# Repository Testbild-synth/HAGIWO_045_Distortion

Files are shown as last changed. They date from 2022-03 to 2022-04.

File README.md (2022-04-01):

# HAGIWO Diode Distortion Eurorack Module
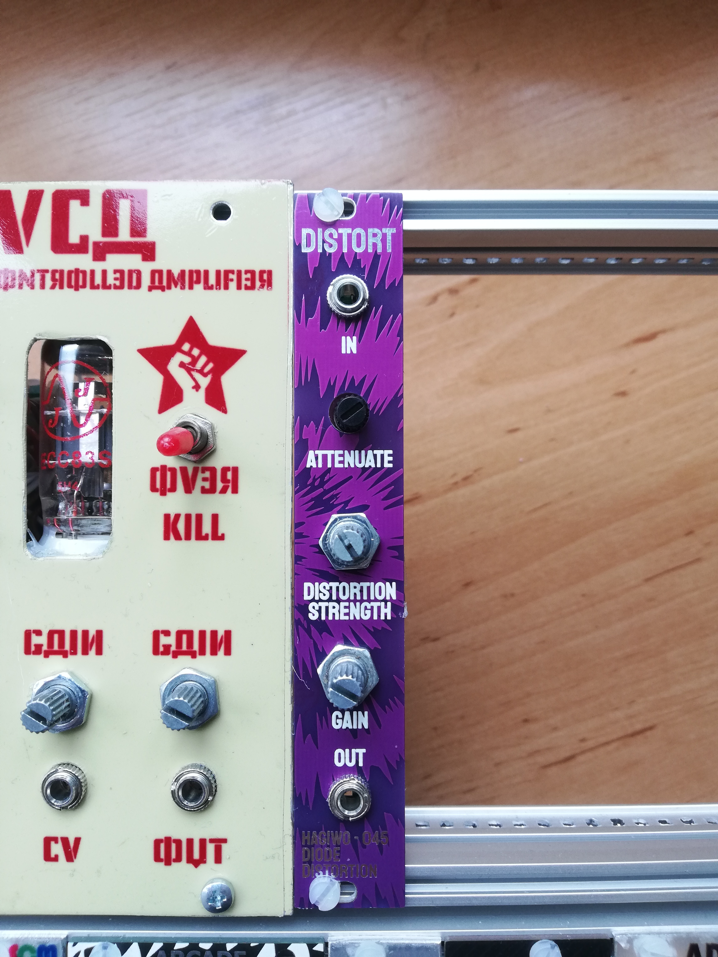
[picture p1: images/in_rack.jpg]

Through-hole 4HP  PCB version of the HAGIWO distortion eurorack module. 

### Current Status: Confirmed working.

## Hardware and PCB

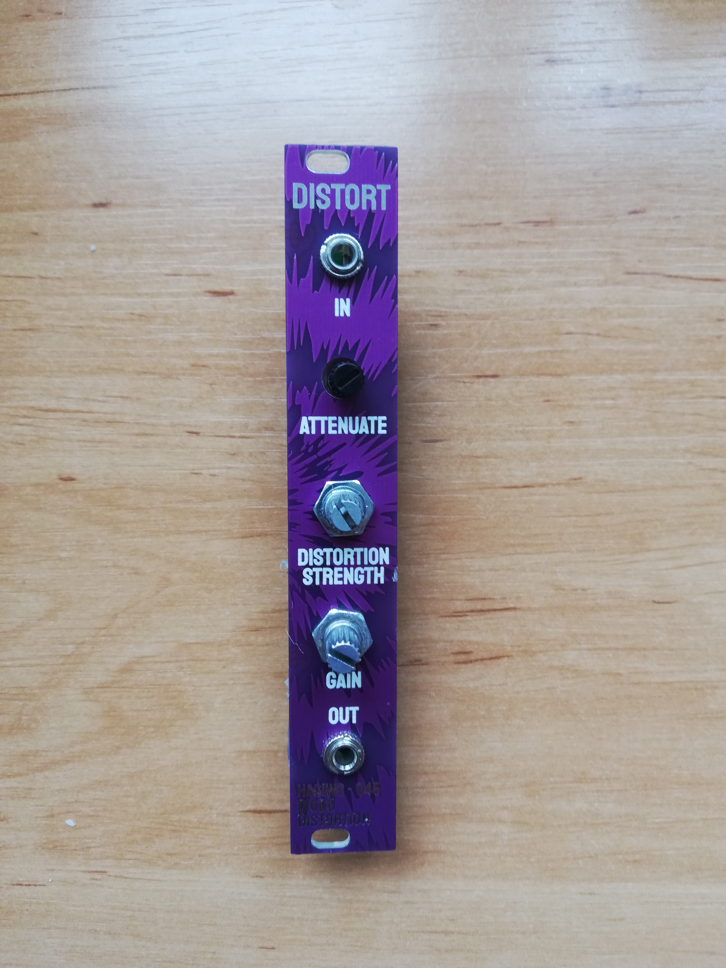
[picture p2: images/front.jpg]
 

You can find the schematic and BOM in the root folder. 
For the PCBs, the module has one circuit PCB and one panel PCB. 
You can order them on any common PCB manufacturing service, I used JLCPCB. For the circuit PCB, standard settings should be fine.
For the panel, since it has copper exposed, make sure to choose a lead free surface finish (LeadFree HASL, ENIG) and/or spraypaint your panels so that you don't get lead on your hands.

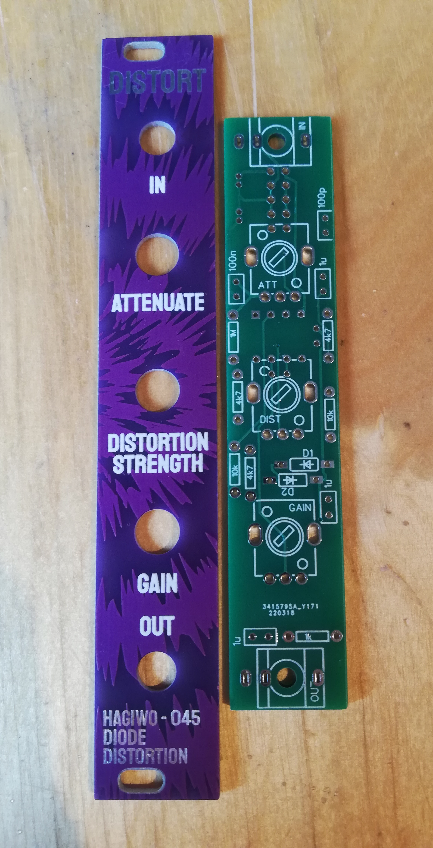
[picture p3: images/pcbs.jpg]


Build is super straight forward, but the 250K Pots specified by HAGIWO can be hard to source. I just used 1M instead, which probably changes how gain and distortion 
behave, but it still works so you can try that instead if you have a hard time sourcing 250k.

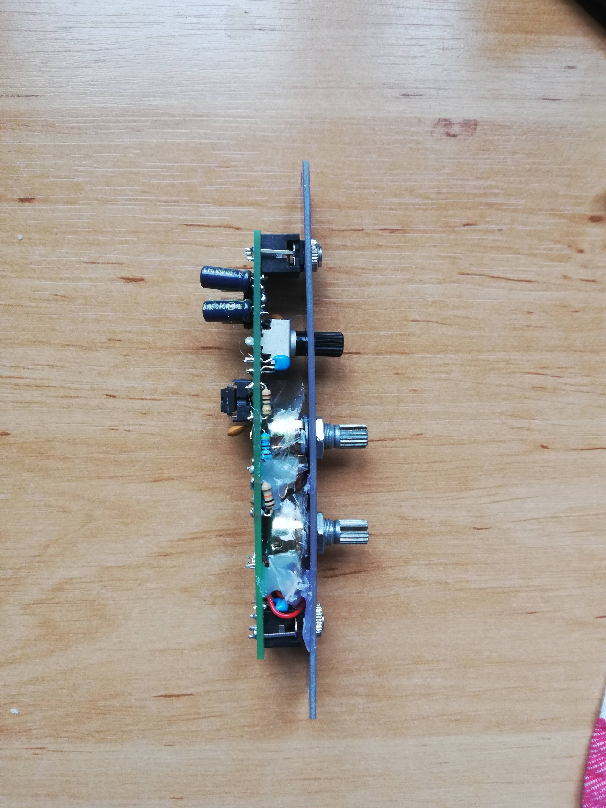
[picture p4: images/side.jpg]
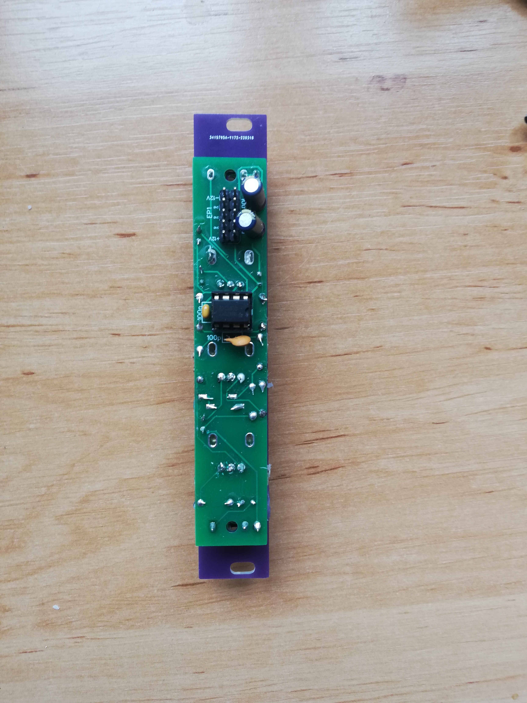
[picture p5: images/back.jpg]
 

## Ideas

One Idea (that I did not try yet but definitely want to) is to exchange the 1n4148 diodes for header sockets or something so you can put in LEDs. Different color LEDs will produce different sound!

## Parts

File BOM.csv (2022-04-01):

Name | Designator | Footprint | Quantity | Comment
R09 Potentiometer 10k | ATT | R09-5KΩ | 1 | 100k is also fine
100p Ceramic Capacitor | C1,C6 | RAD-0.1 | 2
1u Ceramic Capacitor | C2,C5,C7 | RAD-0.1 | 3
10u Electrolytic Capacitor | C3,C4 | CAP-D4.0×F1.5 | 2 | 25V or more is fine
100n Ceramic Capacitor | C8,C9 | RAD-0.1 | 2
1n4148 Diode | D1,D2 | DO35-7 | 2
R09 Potentiometer 250k | DIST,GAIN | R09-5KΩ | 2 | If you are having a hard time sourcing 250K, 1M is also fine. It will change the gains, but I made mine with 1M instead and i like it
EURORACK_POWERHEADER_V2 | EP1 | EURORACK_POWER_V2 | 1
IN, OUT | J1, J2 | THONKICONN_1 | 2
4k7 Resistor | R1,R3,R4 | R_AXIAL-0.3 | 3
10k Resistor | R2,R5 | R_AXIAL-0.3 | 2
1k Resistor | R6 | R_AXIAL-0.3 | 1
1M Resistor | R14 | R_AXIAL-0.3 | 1
TL072BCP | U1 | DIP8 | 1

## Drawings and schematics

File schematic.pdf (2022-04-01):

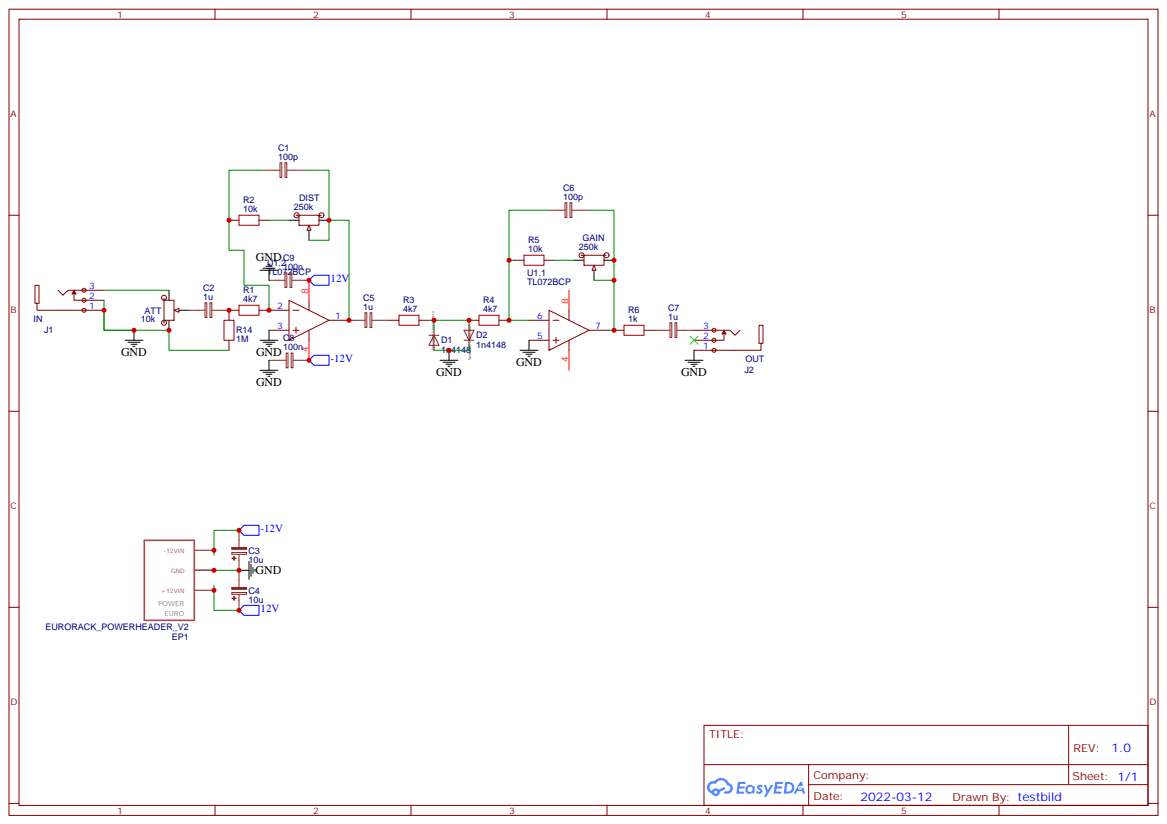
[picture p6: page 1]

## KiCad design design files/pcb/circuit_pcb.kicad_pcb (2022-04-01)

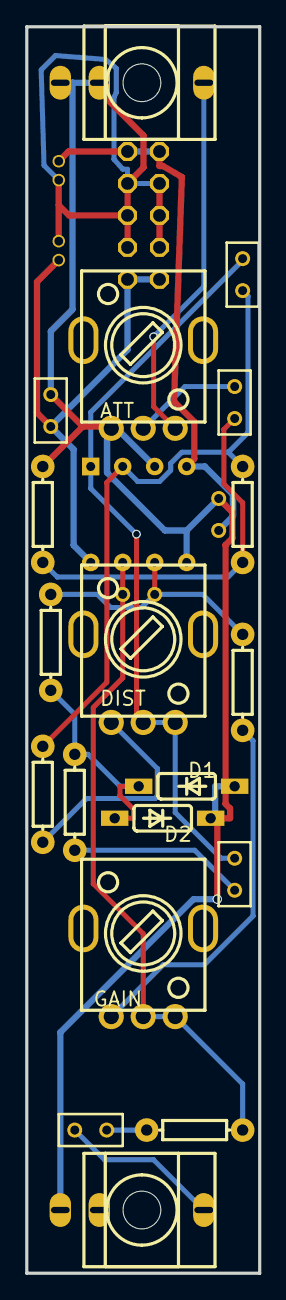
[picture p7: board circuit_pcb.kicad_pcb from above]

Board: 2 copper layers, 18.5 x 99.0 mm, 25 parts (0 on the bottom side), 16 nets.

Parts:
ATT: 10k; R09-5KΩ
C1, C6: 100p; RAD-0.1
C2, C5, C7: 1u; RAD-0.1
C3, C4: 10u; CAP-D4.0×F1.5
C8, C9: 100n; RAD-0.1
D1, D2: 1n4148; DO35-7
DIST: 250k; R09-5KΩ
EP1: EURORACK_POWERHEADER_V2; EURORACK_POWER_V2
GAIN: 250k; R09-5KΩ
J1: IN; THONKICONN_1
J2: OUT; THONKICONN_1
R1, R3, R4: 4k7; R_AXIAL-0.3
R2, R5: 10k; R_AXIAL-0.3
R6: 1k; R_AXIAL-0.3
R14: 1M; R_AXIAL-0.3
U1: TL072BCP; DIP8

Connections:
12V: C4.1, C9.2, EP1.12, U1.8
-12V: C3.2, C8.1, EP1.-12, U1.4
ATT_2: ATT.2, C2.1
ATT_3: ATT.3, J1.3
C2_2: C2.2, R1.2, R14.2
C5_2: C5.2, R3.2
C7_1: C7.1, R6.1
C7_2: C7.2, J2.3
GAIN_1: GAIN.1, R5.1
GND: ATT.1, C3.1, C4.2, C8.2, C9.1, D1.A, D2.C, EP1.GND0, EP1.GND1, EP1.GND2, EP1.GND3, EP1.GND4, EP1.GND5, J1.1, J1.2, J2.1, R14.1, U1.3, U1.5
R2_1: DIST.1, R2.1
R3_1: D1.C, D2.A, R3.1, R4.2
U1_1: C1.2, C5.1, DIST.2, DIST.3, U1.1
U1_2: C1.1, R1.1, R2.2, U1.2
U1_6: C6.1, R4.1, R5.2, U1.6
U1_7: C6.2, GAIN.2, GAIN.3, R6.2, U1.7

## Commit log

2022-03-16 panel upload
    [hagiwo_045_distortion.kicad_pcb]
2022-04-01 updload pcb files
    [circuit_pcb.kicad_pcb]
2022-04-01 upload bom
    [BOM.csv]
